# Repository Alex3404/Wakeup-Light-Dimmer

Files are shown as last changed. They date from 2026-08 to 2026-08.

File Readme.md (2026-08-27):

## Light Dimming on ESP32

A custom designed board using the ESP32 SoC, with an AC Dimming module. Before I get into the details I'd like to cover some of the backstory of this project. During my 2026 semester at my universtity, I had very early classes, and since it was till in the winter the sun doesn't come up by the time I need to wake up. I was reading some information online that waking up to a light is more natural way to wake up since it would memic the typical sun rise/sun set that humans evolved in. So I put that to the test, I had this smart light from Eufy and I programmed it to turn on 20-30minutes before I had to wake up. I saw that I woke up less grogy and more energietic in the mornings. However the biggest con with this approch was that there was no fade option. No way to graudually increase the light only pulse effects. So, I decided to fix this problem myself. I saw that I had an over head light in my room, and a light switch that could be dimmable. Why not combine a sunrise alarm clock with a light switch dimmer? So I got to work. This is project is the result of that question.

## Fully Async Rust Firmware

I landed on the ESP32 for a few main reasons: its direct support for writing in Rust supporting Embassy, its diverse set of peripherals, and that it has WiFI & Bluetooth Module. This repo has the Rust project in its root directory, I've split a few different operations into packages. A application library for unit testing my code, a binary that loads the appliction library on the ESP32, a supporting async storage-derive for the async app state storage driver using the ESP32 NVS partition, and a crate sequental storage built for writing in the format the ESP32 expects.

### Slint UI

My project uses the Slint UI framework for compiling the UI files into the native executable.

## Future Direction for this Project

Currently I'm still working on this project as a solo adventure. If you have issues with it or find any bugs open an issue! I'll get to it. Right now I am still working on the PCB design, Ive gone through 4 iterations now on the PCB, with the last two not working at all for trivial reasons. Once I didn't impedence match the USB data traces to 90 ohms, and another time I shorted the VCC and Ground layers ( Facepalm ). I'm working on PCB design that should work, and will incorperate all my plans.

* Real Time Clock
* SPI Interface for TFT Display
* ESP32
* MOSFET AC Dimming for LCD bulbs
* LiPo battery backup for RTC with intergrated battery charger

I'm also working on the firmware currently I am striving towards getting WIFI and bluethooth to work, then after that I'd love to focus on an Phone application inorder to configure alarm times, and other options exposed though either WIFI or Bluetooth. I'm leaning towards Bluetooth due to WiFi insecurities relating to IoT devices. Supporting only bluetooth should reduce the attack vector.

## Video Showcase
Showcase Video (https://www.youtube.com/watch?v=jobSFEIKs34)

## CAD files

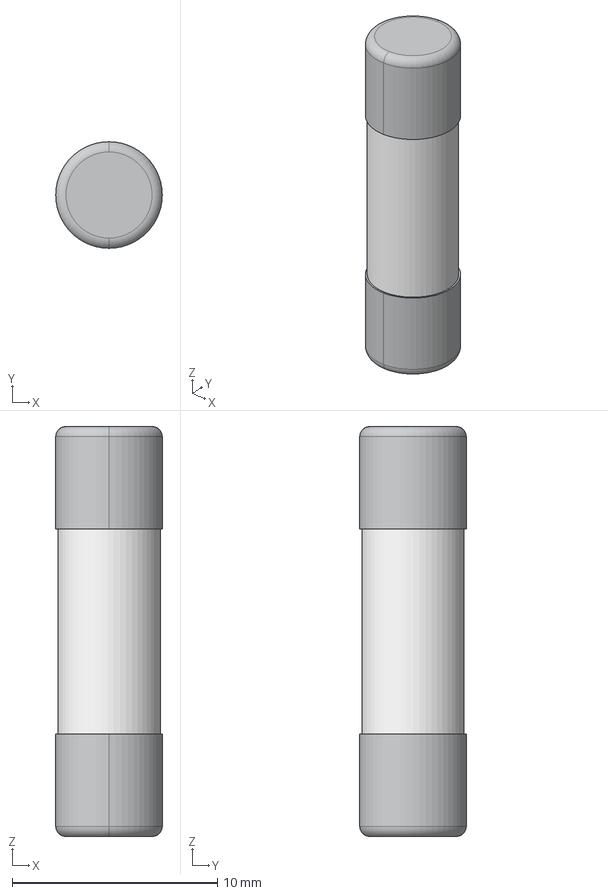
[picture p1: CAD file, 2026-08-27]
board/3D-Models/5x20_250V_v2.step
5.20 x 5.20 x 20.0 mm
FRONT x 2

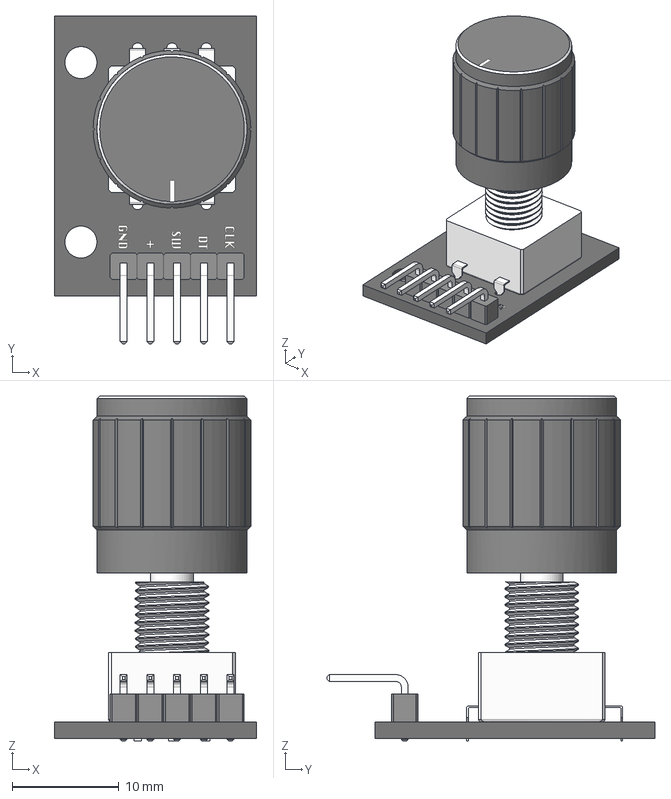
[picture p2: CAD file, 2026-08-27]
board/models/Rotary Encoder - KY-040.step
19.0 x 30.8 x 32.4 mm

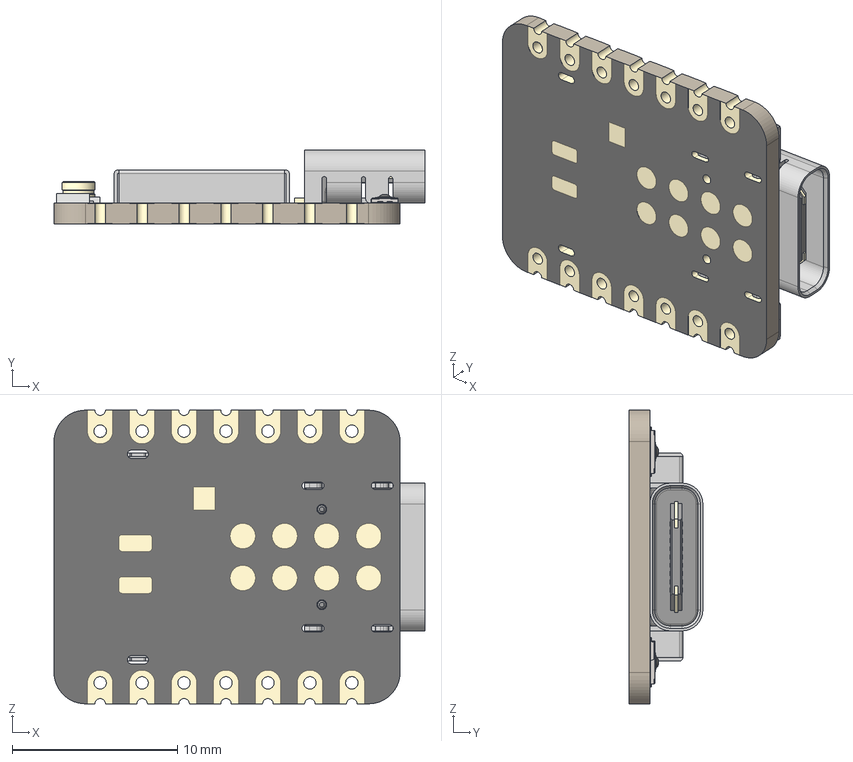
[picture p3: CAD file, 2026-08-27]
board/models/Seeed Studio XIAO ESP32-C6.step
22.5 x 4.46 x 17.8 mm
BOSS-EXTRUDE14_8_
BOSS-EXTRUDE7_4_
BOSS-EXTRUDE7_3_
BOSS-EXTRUDE14_4_
BOSS-EXTRUDE14_2_
BOSS-EXTRUDE14_11_
BOSS-EXTRUDE7_7_
BOSS-EXTRUDE14_9_
BOSS-EXTRUDE14_3_
BOSS-EXTRUDE14_7_
MIRROR2
BOSS-EXTRUDE14_5_
BOSS-EXTRUDE14_12_
BOSS-EXTRUDE7_8_
BOSS-EXTRUDE7_1_
BOSS-EXTRUDE14_10_
BOSS-EXTRUDE7_9_
BOSS-EXTRUDE14_6_
BOSS-EXTRUDE14_1_
BOSS-EXTRUDE7_6_
BOSS-EXTRUDE7_2_
CUT-EXTRUDE5
BOSS-EXTRUDE7_5_
U.FL Connector v1
Shield
SKTAAAE010 x 2
KH5220-A36 (Ceramic Antenna) v2

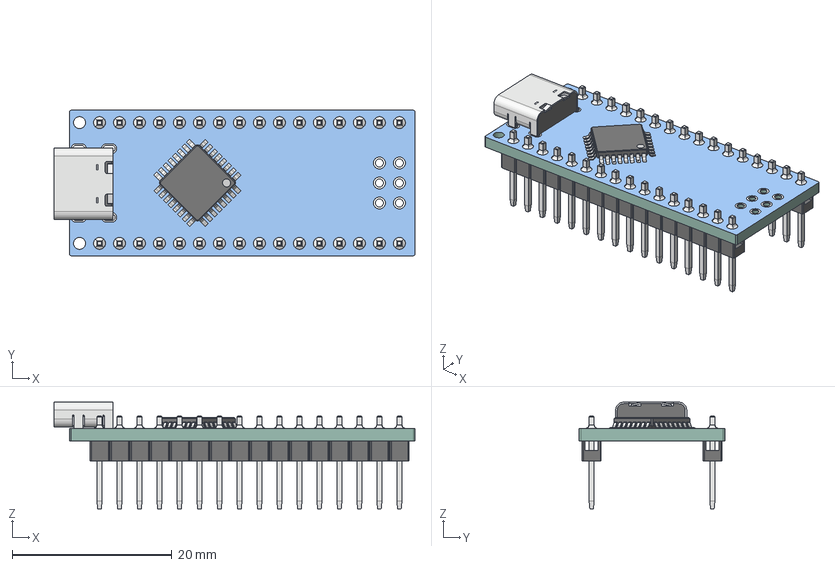
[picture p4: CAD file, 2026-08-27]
board/models/arduinonano.step
45.1 x 18.2 x 13.4 mm
Verbinder Nano Platine x 2
Lötnaht Verbinder Nano x 2
ATMega Chip
TypC Port

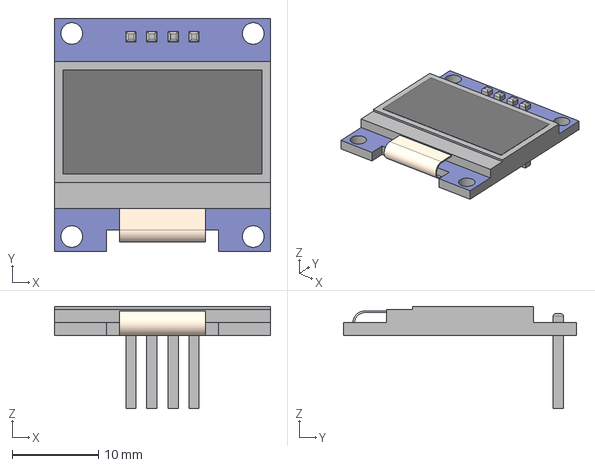
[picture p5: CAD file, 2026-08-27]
board/models/0.9 inch I2C OLED 128×64 Display Module_jhalak.step
25.0 x 27.0 x 11.8 mm

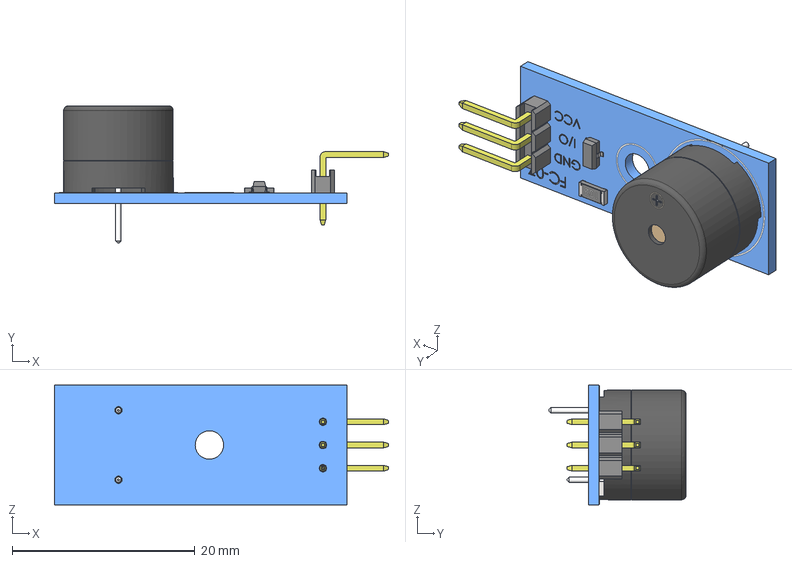
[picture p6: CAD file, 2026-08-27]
board/models/Buzzer Module - FC-07.step
36.5 x 15.0 x 13.1 mm
Pin Header - Single Row - Angled - 2.54 - 3x1
Buzzer Module - FC-07 - PCB
Transist�r - SMD - BC817 NPN - SOT23
Resistor - SMD - 1206

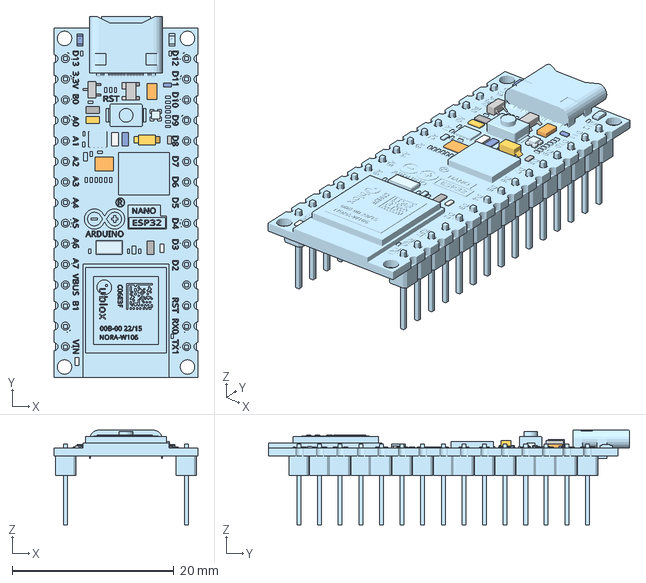
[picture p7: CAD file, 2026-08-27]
board/models/Arduino® Nano ESP32.step
17.8 x 44.6 x 11.7 mm

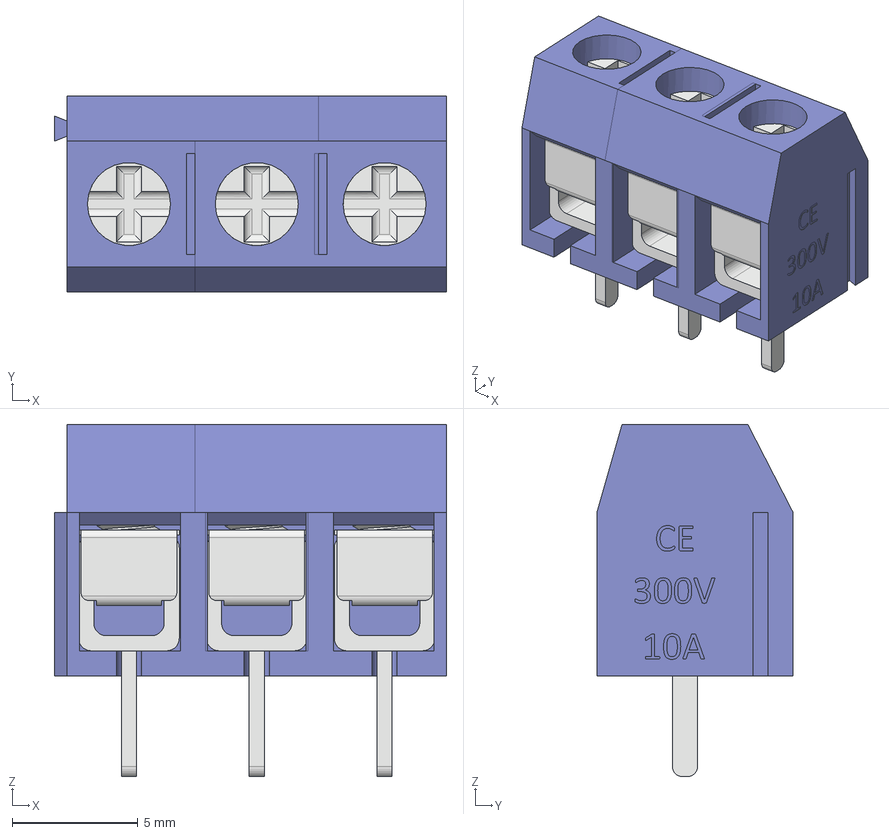
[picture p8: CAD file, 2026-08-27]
board/models/Screw-Terminal-P5.08_3_Pin.step
15.6 x 7.80 x 14.0 mm

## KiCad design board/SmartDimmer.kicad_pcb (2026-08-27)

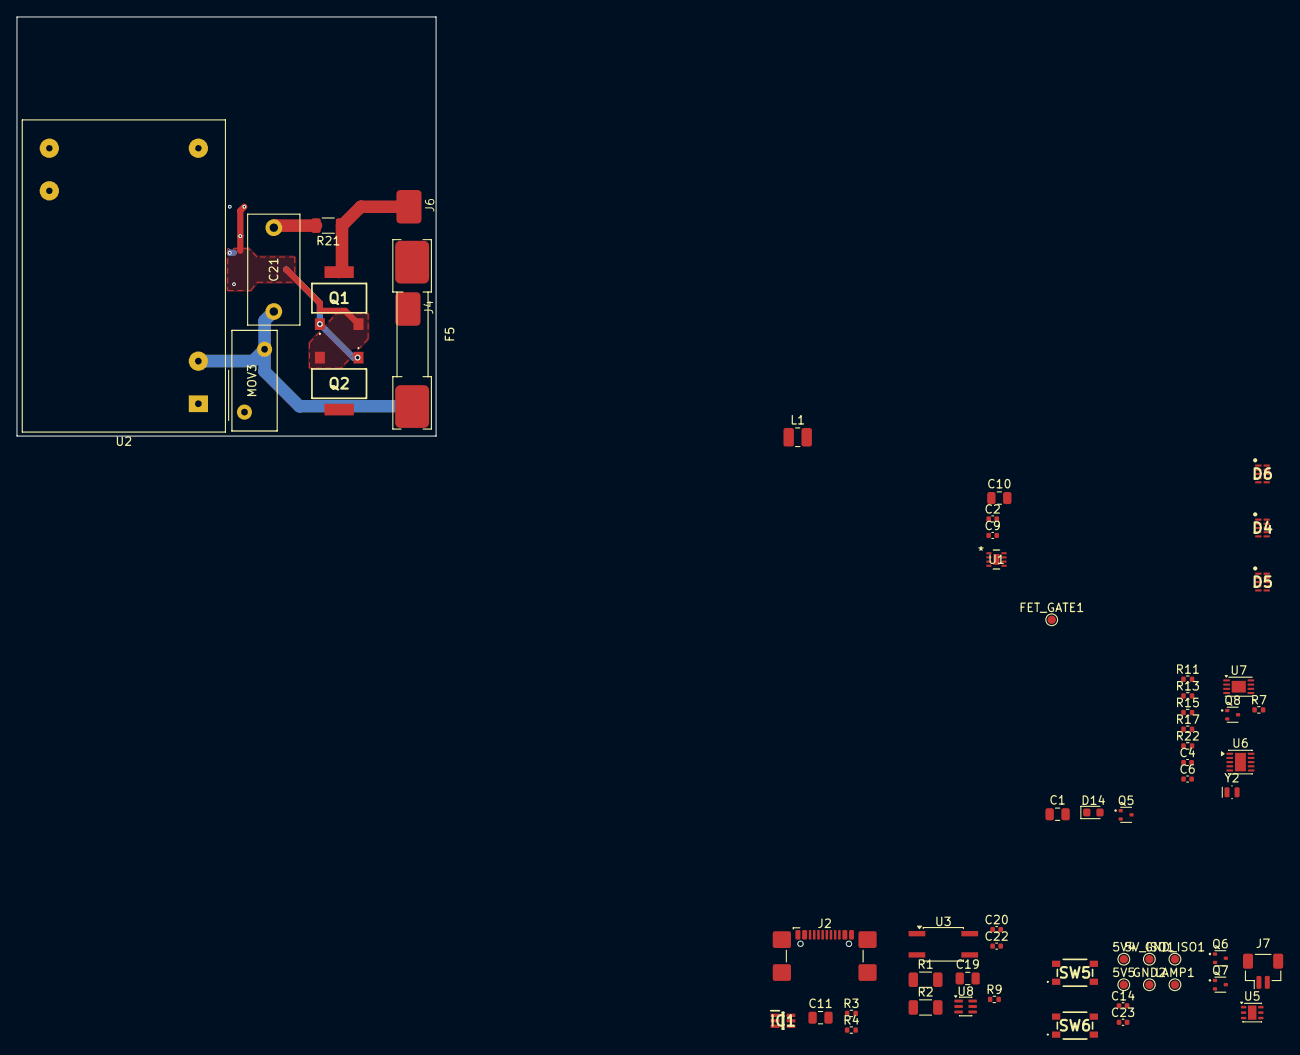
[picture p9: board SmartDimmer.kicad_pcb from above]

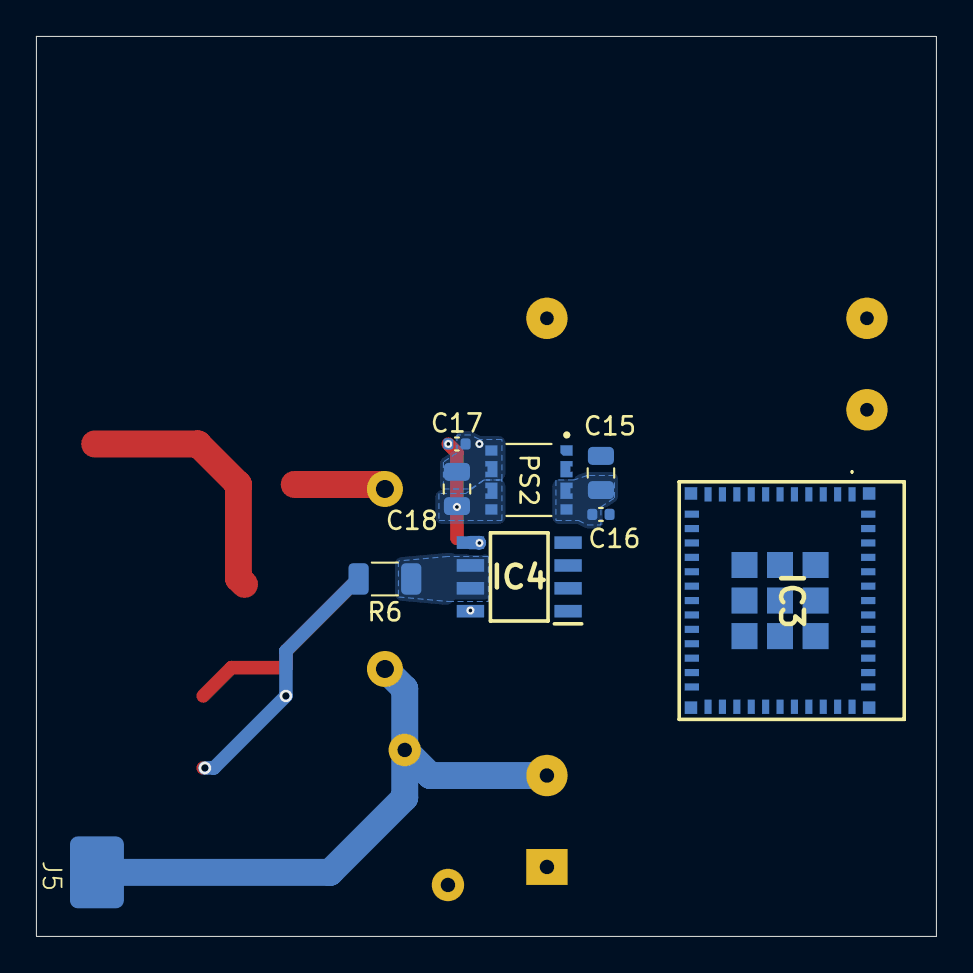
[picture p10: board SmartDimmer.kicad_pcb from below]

Board: 6 copper layers, 50.0 x 50.0 mm, 69 parts (9 on the bottom side), 50 nets.

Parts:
5V4, 5V5, 5V_ISO1: TestPoint; TestPoint_Pad_D1.0mm
C1, C11, C15, C18, C19: 10uF; C_0805_2012Metric
C2: 4.7uF; C_0402_1005Metric
C4, C6: 1uF; C_0402_1005Metric
C9: 520pF; C_0402_1005Metric
C10: 22uF; C_0805_2012Metric
C14, C16, C17, C20, C22, C23: 100nF; C_0402_1005Metric
C21: B32921C3104M000; C_Rect_L13.0mm_W6.0mm_P10.00mm_FKS3_FKP3_MKS4
D4, D5, D6: PUSB3AB4Z; SON50P100X250X50-10N
D14: MAIN_PWR_ST; D_0603_1608Metric
F5: Fuse; 3561KTR_SMD_FUSE_CLIP
FET_GATE1: TestPoint; TestPoint_Pad_D1.0mm
GND2: TestPoint; TestPoint_Pad_D1.0mm
GND_ISO1: TestPoint; TestPoint_Pad_D1.0mm
IC1: NUF2221W1T2G; SOT65P210X110-6N
IC3: ESP32-C6-MINI-1U-H4; ESP32C6MINI1UH4
IC4: 1EDB7275F; SOIC127P600X175-8N
J2: USB-C-16Pin; USB_C_Receptacle_GCT_USB4110
J4, J5, J6: Conn_01x01; Solder_Conn_01x01
J7: BATTERY; JST_SH_BM02B-SRSS-TB_1x02-1MP_P1.00mm_Vertical
L1: 2.2uH; L_1008_2520Metric
LAMP1: TestPoint; TestPoint_Pad_D1.0mm
MOV3: B72210S2271K101; RV_Disc_D12mm_W5.4mm_P7.5mm
PS2: R05C1TF05S-R; CONV_R05C1TF05S-R
Q1, Q2: IPN70R600P7SATMA1
Q5, Q6, Q7, Q8: SSF2320Y; SOT-523
R1, R2: 2/3W 47kΩ; R_1206_3216Metric
R3, R4: 5.1k; R_0402_1005Metric
R6, R21: 100Ω 1W; R_1206_3216Metric
R7: 68K; R_0402_1005Metric
R9: 20k; R_0402_1005Metric
R11, R17, R22: 3.3k; R_0402_1005Metric
R13: 100; R_0402_1005Metric
R15: 10k; R_0402_1005Metric
SW5, SW6: TL3365AF180QG
U1: MIC23050-SYML-TR; MLF-8_ML_MCH-L
U2: IRM-03-5; Converter_ACDC_MeanWell_IRM-03-xx_THT
U3: LTV-354T-A; SO-4_4.4x3.6mm_P2.54mm
U5: NCV68261; DFN-6-1EP_2x2mm_P0.65mm_EP1.01x1.7mm
U6: PCF85063ATL; DFN-10-1EP_2.6x2.6mm_P0.5mm_EP1.3x2.2mm
U7: MCP73831-2-MC; DFN-8-1EP_3x2mm_P0.5mm_EP1.7x1.4mm
U8: NC7WZ14P6X; SOT-363_SC-70-6
Y2: Crystal_Small; Crystal_SMD_MicroCrystal_CM9V-T1A-2Pin_1.6x1.0mm

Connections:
+3.3V: 5V5.1 (1_1), C1.1, C4.1, C9.2, C10.1, C19.1, C20.1, C22.1, D14.2 (A), IC3.3 (3V3), IC4.1 (VDDI), L1.2, R9.2, R11.1, R15.1, R17.1, R22.1, U1.4 (SNS), U8.5 (V_{CC})
+5V: 5V4.1 (1_1), C2.1, C15.1, C16.1, PS2.4_5 (VIN+), PS2.6 (CTRL), U1.2 (EN), U1.7 (VIN), U2.16 (+Vo), U7.1 (V_{DD}), U7.2 (V_{DD})
+5V_ISO: 5V_ISO1.1 (1_1), C17.2, C18.2, IC4.5 (VDDO), PS2.10_11 (VOUT-), PS2.12 (VOUT-)
/AC_Protection1/LINE_IN: F5.1, J4.1 (Pin_1_1)
/A_IN: D5.5 (CH4), IC3.6 (IO3)
/BOOT: C23.1, D6.5 (CH4), IC3.23 (IO9), SW6.3 (K), SW6.4 (A)
/B_IN: D6.1 (CH1), IC3.9 (IO4)
/Battery Charger/+BATT: Q7.3 (D), Q8.1 (G), U5.3 (D), U5.4 (EN), U6.10 (VDD), U7.3 (V_{BAT}), U7.4 (V_{BAT})
/ENCODER_SW: D6.2 (CH2), IC3.10 (IO5)
/ESP32-MCU/LED: IC3.28 (IO22), Q5.1 (G)
/ESP32-MCU/STRAP_GPIO8: IC3.22 (IO8), R17.2
/ESP32-MCU/USB_D+: IC1.4 (D2(C)), IC3.18 (IO13)
/ESP32-MCU/USB_D-: IC1.6 (D1(C)), IC3.17 (IO12)
/Isolated MOSFET Dimmer/FET_GATE: FET_GATE1.1 (1_1), Q1.1 (G), Q2.1 (G), R6.2
/MISO: D4.4 (CH3), IC3.20 (IO15)
/MOSI: D4.2 (CH2), IC3.19 (IO14)
/Protected Battery Connector/+BATT_IN: J7.1, Q6.3 (D)
/RESERVED: D5.4 (CH3), IC3.16 (IO7)
/SCL: D5.2 (CH2), IC3.13 (IO1), R11.2, U6.7 (SCL)
/SCLK: D4.1 (CH1), IC3.24 (IO18)
/SDA: D5.1 (CH1), IC3.12 (IO0), R22.2, U6.6 (SDA)
/USB-C/VBUS: C11.1, IC1.5 (VBUS), J2.A4 (VBUS), J2.A9 (VBUS), J2.B4 (VBUS), J2.B9 (VBUS)
/~LED_CS: D4.5 (CH4), IC3.25 (IO19)
/~RESET: C6.1, C14.1, D6.4 (CH3), IC3.8 (EN), R15.2, SW5.3 (K), SW5.4 (A)
GND: C1.2, C2.2, C4.2, C6.2, C10.2, C11.2, C14.2, C15.2, C16.2, C19.2, C20.2, C22.2, C23.2, D4.3 (GND), D4.8 (GND), D5.3 (GND), D5.8 (GND), D6.3 (GND), D6.8 (GND), GND2.1 (1_1), IC1.2 (GND), IC3.1 (GND), IC3.2 (GND), IC3.11 (GND), IC3.14 (GND), IC3.36 (GND), IC3.37, IC3.38 (GND), IC3.39 (GND), IC3.40 (GND), IC3.41 (GND), IC3.42 (GND), IC3.43 (GND), IC3.44 (GND), IC3.45 (GND), IC3.46 (GND), IC3.47 (GND), IC3.48 (GND), IC3.49 (GND), IC3.50 (GND), IC3.51 (GND), IC3.52 (GND), IC3.53 (GND), IC3.54 (GND), IC3.55 (GND), IC3.56 (GND), IC3.57 (GND), IC3.58 (GND), IC3.59 (GND), IC3.60 (GND), IC3.61 (GND), IC4.3 (IN-), IC4.4 (GNDI), J2.A1 (GND), J2.A12 (GND), J2.B1 (GND), J2.B12 (GND), J2.SH (SHIELD), J7.2, J7.MP (MountPin), PS2.1 (VIN-), PS2.2_3 (VIN-), Q5.2 (S), Q8.2 (S), R3.1, R4.1, SW5.1, SW5.2, SW6.1, SW6.2, U1.6 (AGND), U1.8 (PGND), U1.9, U2.14 (-Vo), U3.3, U5.5 (GND), U6.5 (VSS), U7.6 (V_{SS}), U8.2 (GND)
GND_ISO: C17.1, C18.1, GND_ISO1.1 (1_1), IC4.8 (GNDO), PS2.7 (VSEL), PS2.8_9 (VOUT+), Q1.3 (S), Q2.3 (S)
LAMP_GATE: IC3.27 (IO21), IC4.2 (IN+), LAMP1.1 (1_1)
LINE: F5.2, MOV3.2, Q2.2 (D), R2.1, U2.1 (AC/L)
LOAD: J6.1 (Pin_1_1), Q1.2 (D), R21.1
NEUT: C21.2, J5.1 (Pin_1_1), MOV3.1, R1.1, U2.3 (AC/N)
unnamed: C21.1, R21.2
unnamed: D14.1 (K), R13.2
unnamed: IC1.1 (D1(I)), J2.A7 (D-), J2.B7 (D-)
unnamed: IC1.3 (D2(I)), J2.A6 (D+), J2.B6 (D+)
unnamed: IC4.6 (OUT_SRC), IC4.7 (OUT_SNK), R6.1
unnamed: J2.A5 (CC1), R4.2
unnamed: J2.B5 (CC2), R3.2
unnamed: Q5.3 (D), R13.1
unnamed: Q6.1 (G), Q7.1 (G), U5.2 (G)
unnamed: Q6.2 (S), Q7.2 (S), U5.1 (S), U5.6 (IN)
unnamed: Q8.3 (D), R7.2
unnamed: R1.2, U3.2
unnamed: R2.2, U3.1
unnamed: C9.1, U1.5 (CFF)
unnamed: L1.1, U1.1 (SW)
unnamed: U6.1 (OSCI), Y2.1
unnamed: U6.2 (OSCO), Y2.2
unnamed: R7.1, U7.8 (PROG)
unnamed: R9.1, U3.4, U8.1 (1A)
ZERO_CROSS: IC3.26 (IO20), U8.6 (1Y)

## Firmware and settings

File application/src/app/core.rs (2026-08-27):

extern crate alloc;

use core::cell::RefCell;

use crate::app::ui::slint_ui::DimmerUI;
use crate::drivers::{lamp_dimmer::*};
use crate::drivers::lamp_dimmer::esp_dimmer::{self, *};
use crate::drivers::rotery_decoder::{RoteryDecoder, RoteryDecoderConfig, RoteryInterface};
use crate::persistance::{AsyncStorage, ReactiveAsyncStorage, StorageData};
use crate::app::AppState;

use crate::io::AppPeripherals;
// use crate::app::ui::MenuController;
use crate::persistance::esp_impl::async_nvs_storage;

use embassy_embedded_hal::adapter::BlockingAsync;
use embassy_futures::yield_now;
use embassy_time::Duration;
use esp_hal::gpio::Output;
use esp_radio::wifi::ControllerConfig;
use esp_storage::{FlashStorage};
use fixed::traits::{Fixed, FromFixed};
use fixed::types::{I24F8, U0F16, U16F16};
use pcf85063a::PCF85063;
use embassy_sync::blocking_mutex::raw::NoopRawMutex;
use embassy_sync::watch::{Receiver, Sender, Watch};
use bt_hci::controller::ExternalController;
use esp_hal::{mcpwm::AnyMcPwm};
use esp_radio::{ble::controller::{BleConnector}, wifi::Interfaces};
use sequential_storage::cache::{Cache, Uncached};
use embassy_executor::Spawner;

// App state watcher helper types
const APP_STATE_WATCH_SIZE: usize = 6;
pub type AppStateWatch = Watch<NoopRawMutex, AppState, APP_STATE_WATCH_SIZE>;
pub type AppStateReceiver = Receiver<'static, NoopRawMutex, AppState, APP_STATE_WATCH_SIZE>;
pub type AppStateSender = Sender<'static, NoopRawMutex, AppState, APP_STATE_WATCH_SIZE>;

// Specific timing configuration for our dimmer channel, tuned for our circuit and triac
static PWR_DIMMING_CONFIG: PowerDimmingConfig = PowerDimmingConfig::default()
    .with_dimming_mode(AcDimmingMode::LeadingEdge)
    .with_gate(
        GateConfig::default()
            .with_minimum_gate_time(1500)
            .with_leading_deadtime(500)
            .with_trailing_deadtime(500)
    );


// Type alias for convenience
pub type ReactiveAppStorage = ReactiveAsyncStorage<
    'static, NoopRawMutex, u64,
    BlockingAsync<FlashStorage<'static>>, Cache<Uncached, Uncached, Uncached, u64>,
    AppState, APP_STATE_WATCH_SIZE,
    { AppState::BUFF_SIZE }>;
type AppAsyncStorage = AsyncStorage<NoopRawMutex, u64, BlockingAsync<FlashStorage<'static>>, Cache<Uncached, Uncached, Uncached, u64>>;
type BleController<'a> = ExternalController<BleConnector<'a>, 20>;
type WifiControl<'a> = esp_radio::wifi::WifiController<'a>;

struct Dimmer {
    app_state_sender : AppStateSender,
}

impl Dimmer {
    const ONE_PERCENT : U0F16 = Brightness::FULL.0.checked_div_int(100).unwrap();
}

impl RoteryInterface for Dimmer {
    fn pressed(&self, _pressed: bool) {
        todo!()
    }

    fn rotate_cw(&self, rpm: I24F8) {
        defmt::debug!("Rotating clockwise with rpm: {}", rpm.saturating_to_num::<u16>());
        let increment = U16F16::saturating_from_fixed(rpm)
            .checked_div_int(10).unwrap_or(U16F16::const_from_int(10))
            .saturating_mul(U16F16::checked_from_fixed(Dimmer::ONE_PERCENT).unwrap_or_default());
        let increment = U0F16::checked_from_fixed(increment.frac()).unwrap_or_default();

        self.app_state_sender.send_modify(|state| {
            if let Some(app) = state {
                app.brightness = Brightness(app.brightness.0.saturating_add(increment));
            }
        });
    }

    fn rotate_ccw(&self, rpm: I24F8) {
        defmt::debug!("Rotating counter-clockwise with rpm: {}", rpm.saturating_to_num::<u16>());
        let increment = U16F16::saturating_from_fixed(rpm)
            .checked_div_int(10).unwrap_or(U16F16::const_from_int(10))
            .clamp(U16F16::const_from_int(1), U16F16::const_from_int(20))
            .saturating_mul(U16F16::checked_from_fixed(Dimmer::ONE_PERCENT).unwrap_or_default());
        let increment = U0F16::checked_from_fixed(increment.frac()).unwrap_or_default();

        self.app_state_sender.send_modify(|user_data| {
            if let Some(app_state) = user_data {
                app_state.brightness = Brightness(app_state.brightness.0.saturating_sub(increment));
            }
        });
    }
}

/// App core module that initializes and holds references to all submodules/drivers and shared state
#[allow(unused)]
pub struct App {
    spawner: Spawner,
    // rotery_decoder: RoteryDecoder<'static, Dimmer>,
    // menu_controller: &'static MenuController,

    // App state watch for broadcasting changes to the application state
    state_watch: &'static AppStateWatch,
    // App state receiver for receiving updates to the application state
    state_receiver: AppStateReceiver,

    // Optional these can be unavailable if initialization fails
    main_dimmer: RefCell<Option<BasicDimmer<EspPwmDimmer>>>,
    app_storage: RefCell<Option<AppAsyncStorage>>,
}

impl App {
    /// The main entry point for the application core.
    /// 
    /// Args
    /// - `spawner`: The RTOS task spawner.
    /// - `peripherals`: The application peripherals.
    ///
    /// This function never returns.
    pub async fn main(spawner: Spawner, peripherals: AppPeripherals) -> ! {
        defmt::info!("App main task started!");
        
        // Initialize WiFi controller
        let (mut _wifi_controller, _wifi_interfaces) = Self::init_wifi(peripherals.wifi);

        if let Some(mut _wifi_controller) = _wifi_controller {
            defmt::info!("WiFi controller initialized successfully.");
            _wifi_controller.connect_async().await;
        }

        // Start up bluetooth controller
        let _bluetooth_controller = Self::init_bluetooth(peripherals.bluetooth);

        // Setup application storage and user data
        let mut app_storage = match async_nvs_storage(peripherals.flash) {
            Ok(storage) => Some(storage),
            Err(err) => {
                defmt::error!("Failed to initialize app storage: {:?}", err);
                defmt::error!("No app storage available! Continuing without persistent storage.");
                None
            }
        };
        
        // Init our app state watch
        let mut disable_writes_flag = false;
        let app_state_watch = Self::init_app_state_watch(&mut app_storage, &mut disable_writes_flag).await;

        let reactive_app_storage = if disable_writes_flag {
            defmt::warn!("Disabling app storage due to read error.");
            app_storage = None; // Removed to prevent further writes
            None
        } else {
            defmt::info!("App storage initialized successfully.");
            app_storage.as_ref().map(|app| app.request(app_state_watch.receiver().unwrap()))
        };

        // Initalize the dimmer driver
        esp_dimmer::init(spawner);
        let mcpwm = esp_dimmer::configure_mcpwm(AnyMcPwm::from(peripherals.dimmer.mcpwm));
        let dimmer_config = EspPwmDimmerConfig::new(
            mcpwm,
            peripherals.dimmer.gate.into_peripheral_output(),
            peripherals.dimmer.zero_cross.peripheral_input(),
            true,
            PWR_DIMMING_CONFIG,
        );

        // Attempt to create the ESP PWM dimmer. If it fails, the dimmer will be unavailable.
        let esp_pwm_dimmer = match EspPwmDimmer::new(dimmer_config) {
            Ok(dimmer) => Some(dimmer),
            Err(err) => {
                defmt::warn!("Failed to create ESP PWM dimmer, dimmer will be unavailable: {:?}.", err);
                None
            }
        };

        let main_dimmer = esp_pwm_dimmer.map(|dimmer| {
            defmt::info!("Dimmer initialized!");
            BasicDimmer::new(dimmer, DimmerConfig::default())
        });

        // Initialize the RTC clock
        let _rtc_clock = PCF85063::new(peripherals.i2c_device.clone());

        // Create rotery interface and decoder
        let rotery_dimmer = static_cell::make_static!(Dimmer {
                app_state_sender: app_state_watch.sender(),
            });

        let rotery_config = RoteryDecoderConfig::new(
            peripherals.rotery.clock, peripherals.rotery.rotate, rotery_dimmer, 20
        ).with_switch(peripherals.rotery.switch);

        let rotery_decoder = RoteryDecoder::new(rotery_config);
        defmt::info!("Rotery decoder initialized!");

        let ui = DimmerUI::new(spawner,
            peripherals.i2c_device.clone(),
            app_state_watch.receiver().expect("Increase receiver count!")
        ).await;

        match ui {
            Ok(ui) => {
                defmt::info!("UI initialized successfully");
                spawner.spawn(run_ui(ui).unwrap());
            },
            Err(_) => {
                defmt::error!("Failed to initialize UI");
            }
        }

        let app : &'static mut App = static_cell::make_static!(App {
            spawner,
            // rotery_decoder,
            // menu_controller,
            state_watch: app_state_watch,
            state_receiver: app_state_watch.receiver().expect("Increase receiver count!"),
            app_storage: RefCell::new(app_storage),
            main_dimmer: RefCell::new(main_dimmer),
        });

        defmt::info!("App Created!");

        let bg_tasks = BackgroundTasks {
            rotery_decoder,
            test_led: peripherals.test_led,
            reactive_app_storage,
        };

        app.app_loop(bg_tasks).await;
    }
}

pub struct BackgroundTasks {
    rotery_decoder : RoteryDecoder<'static, Dimmer>,
    test_led : Output<'static>,
    reactive_app_storage: Option<ReactiveAppStorage>,
}

#[embassy_executor::task]
async fn rotery_task(mut rotery_decoder: RoteryDecoder<'static, Dimmer>) {
    rotery_decoder.run_loop().await;
}

impl App {
    /// Main application loop that handles state changes and spawns background tasks.
    async fn app_loop(&'static mut self, bg_tasks: BackgroundTasks) -> ! {
        /// Spawns the background tasks for the application!
        self.spawner.spawn(rotery_task(bg_tasks.rotery_decoder).unwrap());
        self.spawner.spawn(blink_led(bg_tasks.test_led).unwrap());

        // Spawn the reactive storage task if it exists
        if let Some(reactive_app_storage) = bg_tasks.reactive_app_storage {
            self.spawner.spawn(run_reactive_storage(reactive_app_storage).unwrap());
        }

        loop {
            // Wait for changes in the app state
            let new_state = self.state_receiver.changed().await;

            if let Some(ref mut dimmer) = self.main_dimmer.borrow_mut().as_mut() {
                defmt::debug!("New brightness for dimmer: {:?}%", new_state.brightness().0.saturating_to_num::<f32>() * 100.0);
                let _ = dimmer.set_brightness(new_state.brightness());
            }

            // Yield to allow other tasks to run
            yield_now().await;
        }
    }
}

static SSID : &'static str = env!("WIFI_SSID");
static PASSWORD : &'static str = env!("WIFI_PASSWORD");

//============================//
// Application Initialization //
//============================//
impl App {

    /// Initialize the app state watch with the current app state.e
    async fn init_app_state_watch(app_storage : &mut Option<AppAsyncStorage>, disable_writes_flag : &mut bool) -> &'static AppStateWatch {
        use crate::app::app_state::{AppState};
        
        let mut buffer = [0u8; AppState::BUFF_SIZE];
        let app_state = if !*disable_writes_flag {
            if let Some(app_storage) = app_storage {
                app_storage.read_or_default(&mut buffer, AppState::default()).await
            } else {
                Ok(AppState::default())
            }
        } else {
            Ok(AppState::default())
        };

        let app_state = match app_state {
            Ok(state) => state,
            Err(err) => {
                defmt::warn!("Storage error when reading app state: {:?}", err);
                *disable_writes_flag = true; // Disable writes to storage
                AppState::default()
            }
        };

        // App state storage
        let app_state_watch : &'static AppStateWatch = static_cell::make_static!(Watch::new_with(app_state));
        app_state_watch
    }

    /// Initialize the WiFi module with the given peripheral.
    fn init_wifi<'a>(wifi: esp_hal::peripherals::WIFI<'a>) -> (Option<WifiControl<'a>>, Option<Interfaces<'a>>) {
        use esp_radio::wifi::{Config, AuthenticationMethod};
        use esp_radio::wifi::sta::StationConfig;

        let station_config = Config::Station(
            StationConfig::default()
                .with_ssid(alloc::string::String::from(SSID))
                .with_auth_method(AuthenticationMethod::Wpa2Personal)
                .with_password(alloc::string::String::from(PASSWORD))
        );

        let controller_config = ControllerConfig::default();

        match esp_radio::wifi::new(wifi, Default::default()) {
            Ok((ctrl, ifaces)) => {
                defmt::info!("WiFi initialized successfully");
                (Some(ctrl), Some(ifaces))
            },
            Err(e) => {
                defmt::warn!("Failed to initialize wifi: {:?}. Continuing without it", e);
                (None, None)
            },
        }
    }

    /// Initialize the Bluetooth module with the given peripheral.
    fn init_bluetooth<'a>(bluetooth: esp_hal::peripherals::BT<'a>) -> Option<BleController<'a>> {
        let ble_result = BleConnector::new(bluetooth, Default::default()).map(|ble| {
            ExternalController::new(ble)
        });

        match ble_result {
            Ok(ctrl) => {
                defmt::info!("Bluetooth initialized successfully");
                Some(ctrl)
            },
            Err(e) => {
                defmt::warn!("Failed to initialize bluetooth: {:?}. Continuing without it", e);
                None
            },
        }
    }    
}

#[embassy_executor::task]
async fn run_reactive_storage(reactive_app_storage: ReactiveAppStorage) {
    reactive_app_storage.storage_loop().await.unwrap();
}

#[embassy_executor::task]
async fn run_ui(dimmer_ui : DimmerUI) -> () {
    match dimmer_ui.run().await {
        Ok(_) => {
            defmt::warn!("UI loop exited unexpectedly");
        },
        Err(_) => {
            defmt::error!("UI run error");
        }
    };
}

#[embassy_executor::task]
async fn blink_led(mut led: Output<'static>) -> ! {
    loop {
        led.set_high();
        embassy_time::Timer::after(Duration::from_millis(500)).await;
        led.set_low();
        embassy_time::Timer::after(Duration::from_millis(500)).await;
    }
}

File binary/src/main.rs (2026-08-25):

#![no_std]
#![no_main]
#![deny(
    clippy::mem_forget,
    reason = "mem::forget is generally not safe to do with esp_hal types, especially those \
    holding buffers for the duration of a data transfer."
)]
#![deny(clippy::large_stack_frames)]
#![feature(impl_trait_in_assoc_type)]

use application::app_main;
use application::io::{split};

use embassy_executor::Spawner;
use esp_hal::clock::CpuClock;
use panic_rtt_target as _;
use static_cell::StaticCell;

// This creates a default app-descriptor required by the esp-idf bootloader.
// For more information see: <https://docs.espressif.com/projects/esp-idf/en/stable/esp32/api-reference/system/app_image_format.html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>
esp_bootloader_esp_idf::esp_app_desc!();

#[esp_hal::main]
fn main() -> ! {
    static EXECUTOR : StaticCell<esp_rtos::embassy::Executor> = StaticCell::new();
    let executor = EXECUTOR.init(esp_rtos::embassy::Executor::new());

    executor.run(|spawner| {
        spawner.spawn(__async_main(spawner).unwrap());
    })
}

#[embassy_executor::task]
async fn __async_main(spawner: Spawner) -> ! {
    // Configure the ESP32 peripherals and CPU clock
    let config = esp_hal::Config::default().with_cpu_clock(CpuClock::max());
    let peripherals = esp_hal::init(config);

    // Initalize the heap allocator with 72000 bytes of ram
    esp_alloc::heap_allocator!(#[esp_hal::ram(reclaimed)] size: 64000);
    esp_alloc::heap_allocator!(size: 52 * 1024); // Additional heap for general use

    // Initialize the RTT (Real-Time Transfer) for defmt logging
    rtt_target::rtt_init_defmt!();
    defmt::info!("Starting main function");

    let (rtos_peripherals, app_peripherals) = split(peripherals);

    // Start the FreeRTOS scheduler
    esp_rtos::start(rtos_peripherals.rtos_timer, rtos_peripherals.sw_interrupt_0);

    defmt::info!("Starting main application task");
    // Start the main application task
    app_main(spawner, app_peripherals).await
}

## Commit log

2026-03-22 Revision
    Working lamp dimmer and pulse scheduler. Pulse scheduler uses RMT for microsecond precision. Light bulb still flashes occasionally meaning timing is wrong.
    [main.rs]
2026-03-31 Intergrating new MCPWM driver in my esp-hal-mcpwm-cap repo
    Using MCPWM should give me a light dimmer timing that is controlled by hardware, so during wifi/bluetooth operations there will be no flicker.
2026-08-25 Redesinged Dimmer added a trait and esp32 specific impl. Added slint UI
2026-08-27 Added board
    [0.9 inch I2C OLED 128×64 Display Module_jhalak.step, 5x20_250V_v2.step, AC_DC_Power.kicad_sch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]
